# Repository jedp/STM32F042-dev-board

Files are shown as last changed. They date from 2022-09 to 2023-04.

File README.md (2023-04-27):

## STM32F042 Board

Dev board for the
[STM32F042](https://www.st.com/resource/en/datasheet/stm32f042c4.pdf).

Basic linker script, headers, hello world program, and notes are given in [programming](./programming).

Dimensions: 1.63in (41.50mm) x 0.74 in (18.80mm); headers 0.6in (15.24mm) center to center.

USB C receptacle for USB 2.0.

There is also a [Micro-USB version](https://github.com/jedp/STM32F042-dev-board/releases/tag/Micro-USB).

Finished Board

PCB Front Rendering

PCB Back Rendering

## BOM

### USB Section

- J3: USB C USB 2.0 Receptacle, GCT USB4105-xx-A
- U3: USBLC6-2SC6 Power protection, SOT-23-6
- FB1: BK0603HS330-T Ferrite bead, 0805
- R1: 0k DNP, 0603
- R6: 5.1k, 0603
- R7: 5.1k, 0603
- C9: 0.01u, 0805
- C10: 0.1u, 0805
- C11: 4.7u, 1206

Test:

- USB VBUS voltage
- 5V VBUS
- GND
- USB D- at MCU pin 17
- USB D+ at MCU pin 18

### 3V3 Regulator

- U2: MCP1802 3v3 Linear regulator, SOT-23-5
- C1: 1u, 0805
- C3: 10u, 0805
- C5: 1u, 0805
- R5: 1k, 0603
- D2: LED PWR, 0603

Test:

- 3V3 BUS
- 3V3 at MCU pins 5, 16
- GND at MCU pin 15

### Microcontroller

- U1: STM32F042F6Px, TSSOP-20
- C2: 0.1u, 0603
- C4: 0.1u, 0603
- D1: LED USER, 0603
- JP1: Solder Jumper Boot: Solder pad 0 for normal use.
- R3: 10k, 0603
- R4: 1k, 0603
- Reset1: SW Push, SPST B3U-1000P-B

### Headers, JTAG/SWD

- J1: Conn 01x12 Female, PinSocket 2.54mm
- J2: Conn 01x12 Female, PinSocket 2.54mm
- J5: JTAG/SWD, PinHeader 2x05, 1.27mm

Test:

- Flash blinky program
- Resest using Reset1

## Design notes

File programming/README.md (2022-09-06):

# Programming Notes

## Blinky

Use `hello.c` to blink the PB1 LED on the board.

Adjust `Makefile` as necessary for toolchain and versions.

```
make
```

Flash `main.hex` with `st-flash` or `JFlashLite`.

## Application Note Notes

### MCO Selection Code Example

RN0091, Appendix A.3.3, gives this one-line example:

```
/* Select system clock to be output on the MCO without prescaler */
RCC->CFGR |= RCC_CFGR_MCO_SYSCLK;
```

On this board, a little more work is required. First, we must establish the MCO pin. This information is in the
data sheet, Table 14: Alternate functions selected through GPIOA_AFR registers for port A.

Here we see that MCO can either be AF0 on PA8 or AF5 on PA9. This TSSOP20 does not have a pin PA8, so we must configure
PA9 to the correct alternate mode. Back in the programming reference, Table 8.4.10 lists the register values for
GPIO alternate functions (higher register because we are using PA9). AF5 is `0101`.

So to output the MCO on PA9, the complete setup code is:

```
RCC_AHBENR |= BIT_17;           // PORTA IO enable
RCC_CFGR |= (BIT_26 | BIT_24);  // Bits27:24 MCO[3:0] 0101: Internal RC 8 MHz (HSI) oscillator clock selected
GPIOA_MODER |= BIT_19;          // PA9: Enable alternate function mode
GPIOA_AFRH |= (BIT_6 | BIT_4);  // PA9: Configure alternate function mode 5
```

My oscilloscope measures VPP 3.76 to 3.80 and Freq 7.987 to 8.013 MHz.

### Delay Function using general-purpose timer.

Implementation of `void delay(int ms)` using TIM14.

AN4776, Section 1.3.1, Timer time-base configuration, demonstrates the basic scheme of things, though as always it's a
bit elliptical about what needs to be enabled for anything to work.

Here is a complete implementation:

```
static void delay_ms(int millis) {
    // Delay implemented using TIM14.
    // TIM14 is a general purpose timer with the added bonus that it consumes the least current.
    // See datasheet Table 32, Peripheral current consumption. TIM14 consumes 5.5 uA / MHz.

    // Enable TIM14 for use as our delay timer.
    RCC_APB1ENR |= BIT_8;

    TIM14_SR = 0;
    TIM14_PSC = 8 * 1000 - 1;
    TIM14_ARR = millis;
    TIM14_CR1 |= BIT_0;             // Start the timer counter
    while (!(TIM14_SR & BIT_0));    // While UIF not set
}
```

## References

This was my first attempt at writing stm32 code without an IDE (i.e., without CubeMX generating all the low-level code
for me). I found the following references very helpful:

- https://ioprog.com/arm-cortex/the-linker-script-file/
- https://blog.thea.codes/the-most-thoroughly-commented-linker-script/
- https://freeelectron.ro/bare-metal-stm32-led-blink/

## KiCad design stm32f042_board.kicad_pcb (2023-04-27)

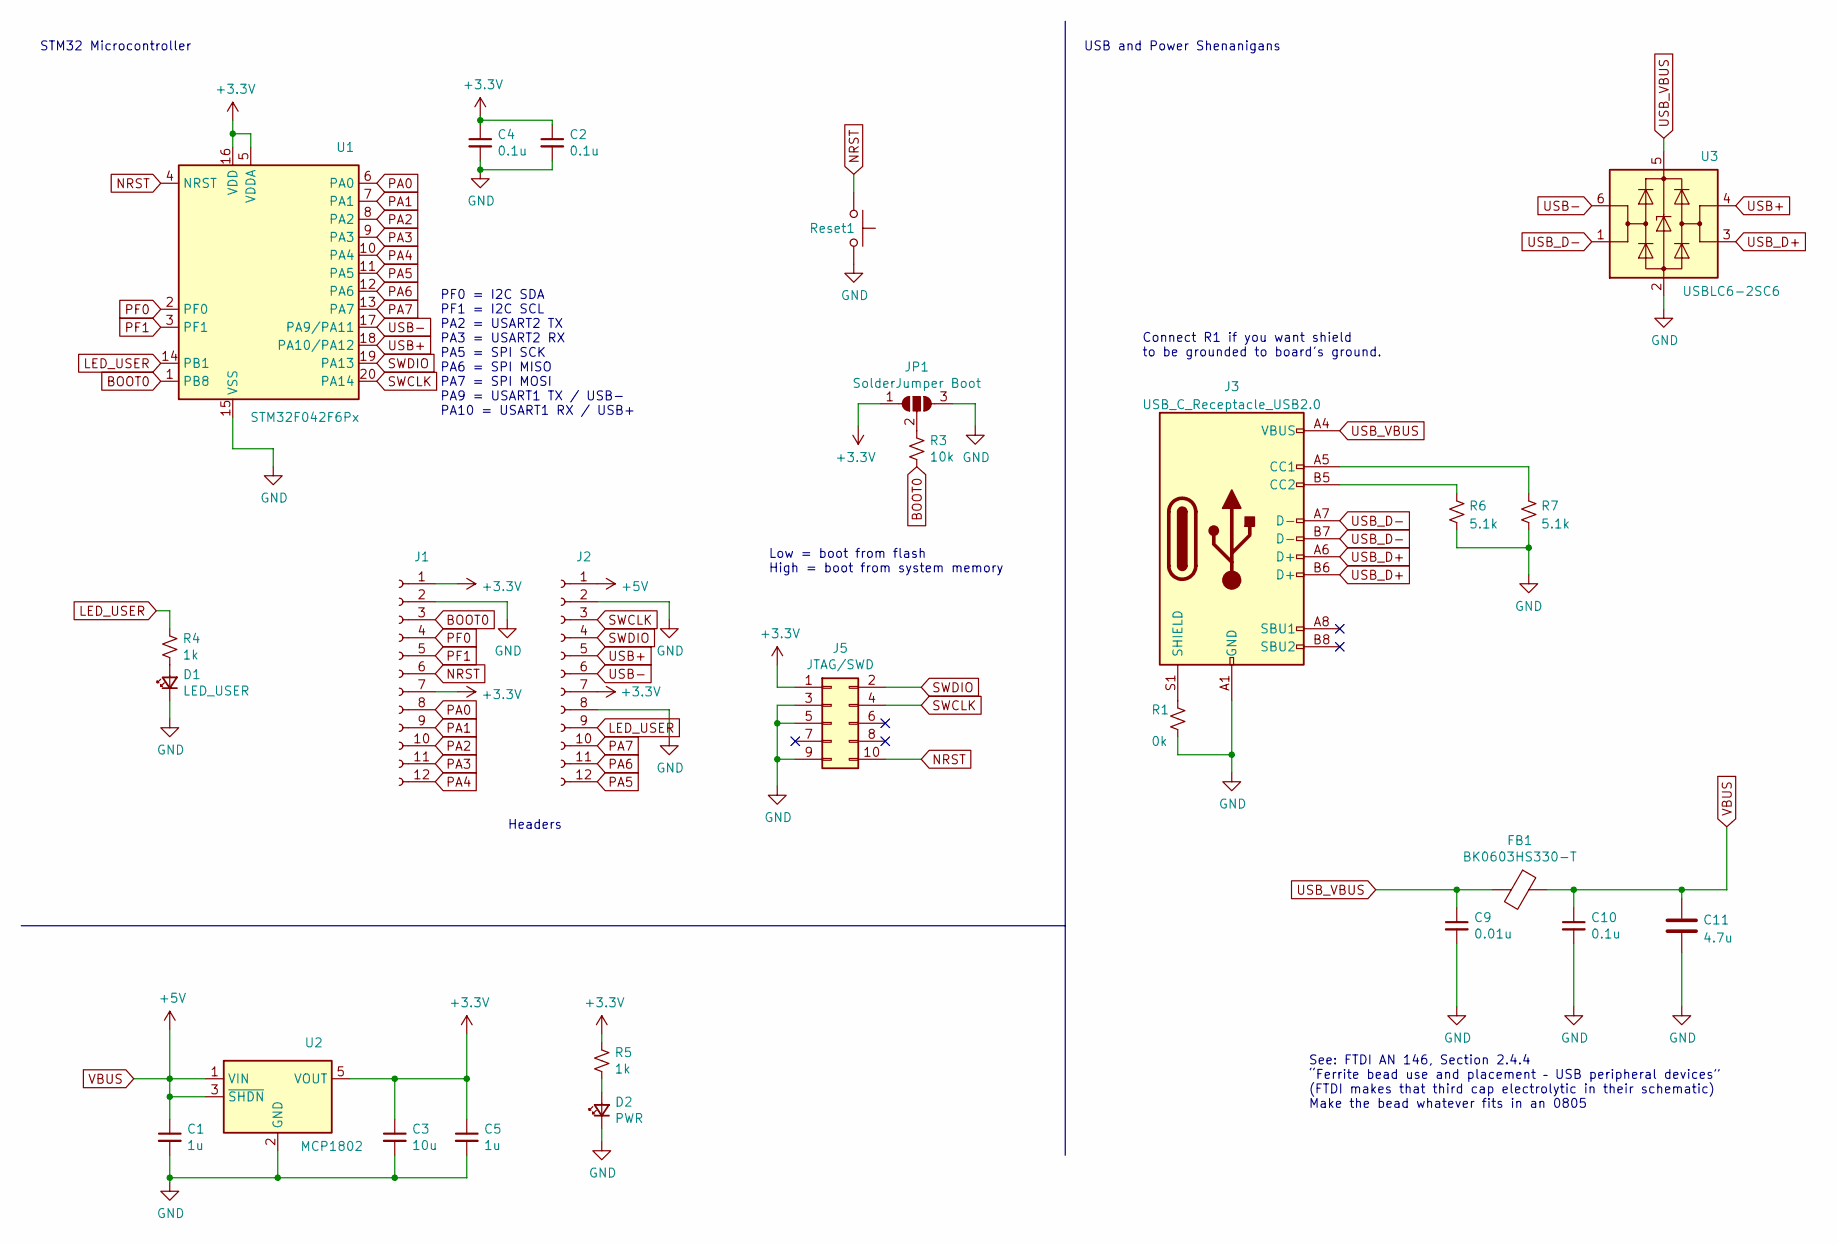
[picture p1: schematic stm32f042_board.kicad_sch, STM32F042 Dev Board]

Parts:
C1, C5: 1u; C_0805_2012Metric
C2, C4: 0.1u; C_0603_1608Metric
C3: 10u; C_0805_2012Metric
C9: 0.01u; C_0805_2012Metric
C10: 0.1u; C_0805_2012Metric
C11: 4.7u; C_1206_3216Metric
D1: LED_USER; LED_0603_1608Metric
D2: PWR; LED_0603_1608Metric
FB1: BK0603HS330-T; L_0805_2012Metric
J1, J2: Conn_01x12_Female; PinSocket_1x12_P2.54mm_Vertical
J3: USB_C_Receptacle_USB2.0; USB4105-GF-A
J5: JTAG/SWD; PinHeader_2x05_P1.27mm_Vertical
JP1: SolderJumper Boot; SolderJumper-3_P2.0mm_Open_TrianglePad1.0x1.5mm
R1: 0k; R_0603_1608Metric
R3: 10k; R_0603_1608Metric
R4, R5: 1k; R_0603_1608Metric
R6, R7: 5.1k; R_0603_1608Metric
Reset1: SW_Push; SW_SPST_B3U-1000P-B
U1: STM32F042F6Px; TSSOP-20_4.4x6.5mm_P0.65mm
U2: MCP1802; SOT-23-5
U3: USBLC6-2SC6; SOT-23-6

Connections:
+3V3: C2.1, C3.1, C4.1, C5.1, J1.1, J1.7, J2.7, J5.1, JP1.1 (A), R5.1, U1.5 (VDDA), U1.16 (VDD), U2.5 (VOUT)
BOOT0: J1.3, R3.2, U1.1 (PB8)
GND: C1.2, C2.2, C3.2, C4.2, C5.2, C9.2, C10.2, C11.2, D1.1 (K), D2.1 (K), J1.2, J2.2, J2.8, J3.A1 (GND), J3.A12 (GND), J3.B1 (GND), J3.B12 (GND), J5.3, J5.5, J5.9, JP1.3 (B), R1.2, R6.2, R7.2, Reset1.2, U1.15 (VSS), U2.2 (GND), U3.2 (GND)
LED_USER: J2.9, R4.1, U1.14 (PB1)
NRST: J1.6, J5.10, Reset1.1, U1.4 (NRST)
unnamed: D1.2 (A), R4.2
unnamed: D2.2 (A), R5.2
unnamed: J3.A5 (CC1), R7.1
unnamed: J3.B5 (CC2), R6.1
unnamed: J3.S1 (SHIELD), R1.1
unnamed: JP1.2 (C), R3.1
PA0: J1.8, U1.6 (PA0)
PA1: J1.9, U1.7 (PA1)
PA2: J1.10, U1.8 (PA2)
PA3: J1.11, U1.9 (PA3)
PA4: J1.12, U1.10 (PA4)
PA5: J2.12, U1.11 (PA5)
PA6: J2.11, U1.12 (PA6)
PA7: J2.10, U1.13 (PA7)
PF0: J1.4, U1.2 (PF0)
PF1: J1.5, U1.3 (PF1)
SWCLK: J2.3, J5.4, U1.20 (PA14)
SWDIO: J2.4, J5.2, U1.19 (PA13)
USB+: J2.5, U1.18 (PA10/PA12), U3.4 (I/O2)
USB-: J2.6, U1.17 (PA9/PA11), U3.6 (I/O1)
USB_D+: J3.A6 (D+), J3.B6 (D+), U3.3 (I/O2)
USB_D-: J3.A7 (D-), J3.B7 (D-), U3.1 (I/O1)
USB_VBUS: C9.1, FB1.2, J3.A4 (VBUS), J3.A9 (VBUS), J3.B4 (VBUS), J3.B9 (VBUS), U3.5 (VBUS)
VBUS: C1.1, C10.1, C11.1, FB1.1, J2.1, U2.1 (VIN), U2.3 (~SHDN)

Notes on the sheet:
Headers
Connect R1 if you want shield to be grounded to board's ground.
PF0 = I2C SDA PF1 = I2C SCL PA2 = USART2 TX PA3 = USART2 RX PA5 = SPI SCK PA6 = SPI MISO PA7 = SPI MOSI PA9 = USART1 TX / USB- PA10 = USART1 RX / USB+
STM32 Microcontroller
USB and Power Shenanigans
See: FTDI AN 146, Section 2.4.4 “Ferrite bead use and placement – USB peripheral devices” (FTDI makes that third cap electrolytic in their schematic) Make the bead whatever fits in an 0805
Low = boot from flash High = boot from system memory

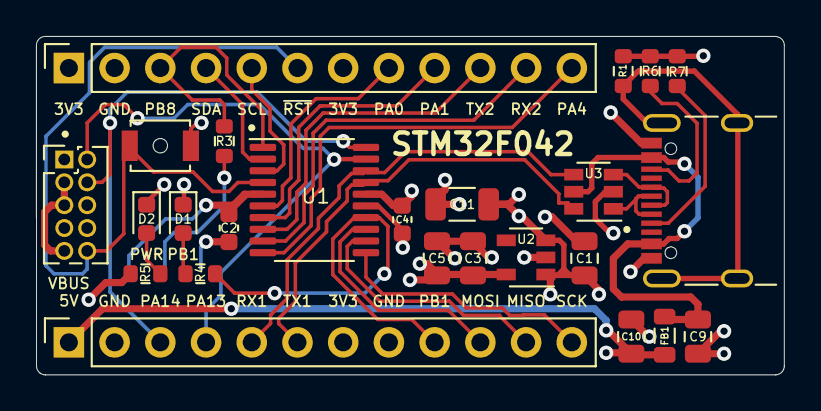
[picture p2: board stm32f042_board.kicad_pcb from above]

Board: 4 copper layers, 41.6 x 18.8 mm, 26 parts (1 on the bottom side), 29 nets.

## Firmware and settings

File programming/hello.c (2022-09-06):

#include "stm32f042f6p6.h"
#include "main.h"

/*
 * Blink the on-board LED, which is PB1.
 */

static void setup(void) {
    // Enable peripheral clock for PORTB.
    RCC_AHBENR |= BIT_18;

    // Set mode to 01 (output) for PB1.
    GPIOB_MODER |= BIT_2;
    GPIOB_MODER &= ~BIT_3;

    // We can now blink the LED on PB1 by toggling bit 1 on GPIOB_ODR.
}

static void delay_ms(int millis) {
    // Delay implemented using TIM14.
    // TIM14 is a general purpose timer with the added bonus that it consumes the least current.
    // See datasheet Table 32, Peripheral current consumption. TIM14 consumes 5.5 uA / MHz.

    // Enable TIM14 for use as our delay timer.
    RCC_APB1ENR |= BIT_8;

    TIM14_SR = 0;                   // Reset status register. (Cancel UIF etc.)
    TIM14_PSC = 8 * 1000 - 1;
    TIM14_ARR = millis;
    TIM14_CR1 |= BIT_0;             // Start the timer counter
    while (!(TIM14_SR & BIT_0));    // Wait until update interrupt flag is set.
}

int main() {
    setup();

    while (1) {
        // Pin 1 on.
        GPIOB_ODR |= BIT_1;
        delay_ms(1000);

        // Pin 1 off.
        GPIOB_ODR &= ~BIT_1;
        delay_ms(1000);
    }
}

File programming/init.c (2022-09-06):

#include "stm32f042f6p6.h"
#include "main.h"

static void init(void);

static void Default_Handler(void);

/* Linker script declarations. */
extern unsigned char INIT_DATA_VALUES;
extern unsigned char INIT_DATA_START;
extern unsigned char INIT_DATA_END;
extern unsigned char BSS_START;
extern unsigned char BSS_END;
extern unsigned char _stack_top;

/* Vectors installed at beginning of flash by the linker script. */
const void *isr[] __attribute__((section(".vectors"))) = {
        &_stack_top,        /* Top of stack. */
        init,               /* 0x0000 0004: Reset Handler */
        Default_Handler,    /* 0x0000 0008: NMI (RCC clock security, RAM parity check) */
        Default_Handler,    /* 0x0000 000c: HardFault (all classes of fault) */
        Default_Handler,
        Default_Handler,
        Default_Handler,
        Default_Handler,
        Default_Handler,
        Default_Handler,
        Default_Handler,
        Default_Handler,    /* 0x0000 002c: System service call via SWI */
        Default_Handler,
        Default_Handler,
        Default_Handler,    /* 0x0000 0038: Pendable request for system service */
        Default_Handler,    /* 0x0000 003c: SysTick */

        /* External interrupt handlers start at 0x0000 0040. */
        Default_Handler,    /* 0: WWDG */
        Default_Handler,    /* 1: PVD and VDDIO2 supply comparator interrupt */
        Default_Handler,    /* 2: RTC */
        Default_Handler,    /* 3: FLASH */
        Default_Handler,    /* 4: RCC_CRS */
        Default_Handler,    /* 5: EXTI0_1 */
        Default_Handler,    /* 6: EXTI2_3 */
        Default_Handler,    /* 7: EXTI4_15 */
        Default_Handler,    /* 8: TSC */
        Default_Handler,    /* 9: DMA_CH1 */
        Default_Handler,    /* 10: DMA_CH2_3, DMA2_CH1_2 */
        Default_Handler,    /* 11: DMA_CH4_5_6_7, DMA2_CH3_4_5 */
        Default_Handler,    /* 12: ADC_COMP */
        Default_Handler,    /* 13: TIM1_BRK_UP_TRG_COM */
        Default_Handler,    /* 14: TIM1_CC */
        Default_Handler,    /* 15: TIM2 */
        Default_Handler,    /* 16: TIM3 */
        Default_Handler,    /* 17: TIM6_DAC*/
        Default_Handler,    /* 18: TIM7 */
        Default_Handler,    /* 19: TIM14 */
        Default_Handler,    /* 20: TIM15 */
        Default_Handler,    /* 21: TIM16 */
        Default_Handler,    /* 22: TIM17 */
        Default_Handler,    /* 23: I2C1 */
        Default_Handler,    /* 24: I2C2 */
        Default_Handler,    /* 25: SPI1 */
        Default_Handler,    /* 26: SPI2 */
        Default_Handler,    /* 27: USART1 */
        Default_Handler,    /* 28: USART2 */
        Default_Handler,    /* 29: USART3_4_5_6_7_8 */
        Default_Handler,    /* 30: CEC_CAN */
        Default_Handler     /* 31: USB */
};

void init() {
    unsigned char *src;
    unsigned char *dest;
    unsigned len;

    // Global / static initialization.
    src = &INIT_DATA_VALUES;
    dest = &INIT_DATA_START;
    len = &INIT_DATA_END - &INIT_DATA_START;
    while (len--)
        *dest++ = *src++;

    // Zero out BSS.
    dest = &BSS_START;
    len = &BSS_END - &BSS_START;
    while (len--)
        *dest++ = 0;

    main();
}

void Default_Handler() {
    while (1);
}

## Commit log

2021-02-10 jedboard v2
    [stm32f042_board.kicad_pcb, stm32f042_board.sch]
2021-03-03 move a via to reconnect the isolated 3V3 and GND pours (pins 1 and 2)
    [stm32f042_board.kicad_pcb]
2021-03-18 oops. connect 3v3 on jtag header.
    [stm32f042_board.kicad_pcb, stm32f042_board.sch]
2021-03-18 make smaller
    [stm32f042_board.kicad_pcb]
2023-03-07 Fix user LED ground; Update kicad version
    [stm32f042_board.kicad_pcb]
2023-03-07 Add identifying text on rear silkscreen
    [stm32f042_board.kicad_pcb]
2023-04-09 Bug fixes
    - Un-migrate to v7 - oshpark not compatibile yet
    - Optionally ground USB shield to board via R 0k
    - Route Tx/Rx (USB D+/-) as diff pair to breakout pins
    - Fix missing +3V3 connection to JTAG pin 1
    - Four-layer board
    - Remove unnecessary gaps in copper now that board is four layers
    [stm32f042_board.kicad_pcb, stm32f042_board.kicad_sch, stm32f042_board.sch]
2023-04-27 Replace USB Micro receptacle with USB C
    [stm32f042_board.kicad_pcb, stm32f042_board.kicad_sch]
2023-04-27 Add BOM and component groups to readme
2023-04-27 Finished board photo (USB-C)
